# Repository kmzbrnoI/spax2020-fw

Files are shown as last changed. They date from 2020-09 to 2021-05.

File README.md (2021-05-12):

# SPAX 2020

[SPAX](http://fremodcc.sourceforge.net/booster/spaxbooster/index.html)
is a model-railroad DCC signal booster. It is a [well-known hardware
construction from FREMO model railroaders club in
Germany](http://fremodcc.sourceforge.net/booster/spaxbooster/index.html).
This repository contains firmware and PCB design for a new
processor PIC12F629 which is supposed to replace original PIC12F508 SPAX v2
processor **without** changing whole SPAX pcb.

This is a low-cost solution for eliminating old-processor disadvantages.
For future expansion (RailCom etc.) whole new SPAX should be designed.

## Why to change processor?

1. **Weird shortcut detection**
   The old processor measured current as analog signal on digital CPU input.
   This caused bad detection sometimes. The new processor reads analog input
   and uses internal comparator.

2. **Short shortcut-restore time**
   The old processor indicated shortcut when e. g. cars with larger capacitors
   were put on a track. When new processor detects shortcut, it leaves max
   current for a longer time – 20 ms. This is enough time for capacitors to
   charge.

## How to change processor in SPAX

Manufacture `12F629.brd` PCB and replace DIL8 old processor with SMD new
processor on the board.

## Firmware functionality description

Track power supply is restored after 200 ms, 400 ms, 800 ms, 1200 ms, 1200 ms,
...  after overcurrent is detected. This is long-enough time for SPAX cooler to
cool-down stabilizer and H-bridge.

H-bridge ensures that shortcut current will never be more than 3 A.

First 3 tests for overcurrent-restore allow only 5 ms of max current, all next
tests allow max current for 20 ms.

## LEDs

* Red LED = not generating DCC on output
* Green LED = DCC on input

States:

* Green: generating DCC to track
* Red: DCC on input present, but shortcut detected
* Yellow: DCC not on input

## Authors

 * hardware: Jan Horacek
 * firmware: Michal Petrilak, Jan Horacek

## License

The firmware and PCB design is distributed as opensource project under
Apache License v2.0.

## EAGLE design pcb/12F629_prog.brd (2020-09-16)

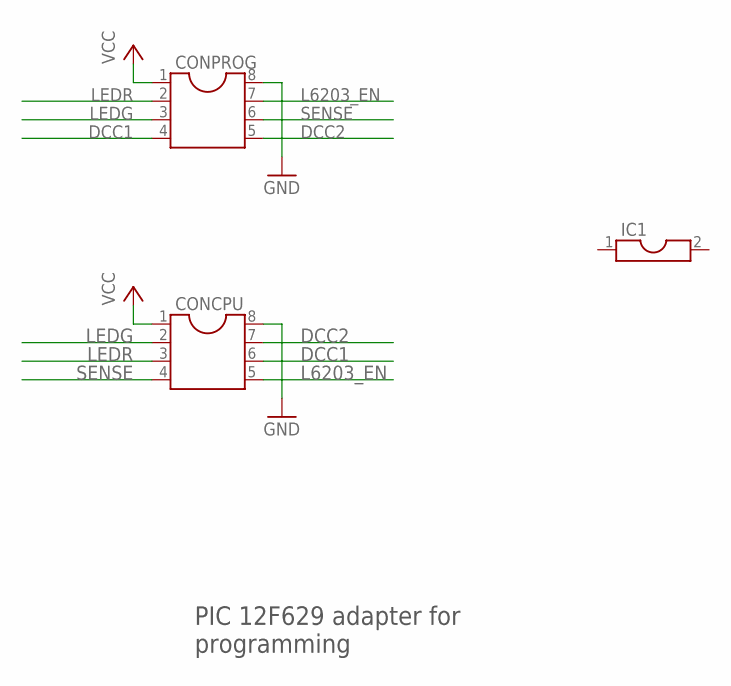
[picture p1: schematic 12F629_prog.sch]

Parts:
CONCPU: DIL8; DIL08
CONPROG: DIL8; DIL08
IC1: DIL2; DIL02

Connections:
DCC1: CONCPU.6, CONPROG.4
DCC2: CONCPU.7, CONPROG.5
GND: CONCPU.8, CONPROG.8
L6203_EN: CONCPU.5, CONPROG.7
LEDG: CONCPU.2, CONPROG.3
LEDR: CONCPU.3, CONPROG.2
SENSE: CONCPU.4, CONPROG.6
VCC: CONCPU.1, CONPROG.1

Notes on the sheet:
PIC 12F629 adapter for programming

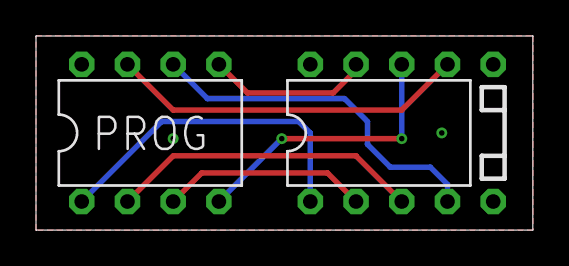
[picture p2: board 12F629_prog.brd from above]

Board: 2 copper layers, 27.6 x 10.8 mm, 3 parts (0 on the bottom side), 8 nets.

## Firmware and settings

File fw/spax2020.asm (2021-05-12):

;      SPAX2020
; ---------------------
; Spax s lépe řešenou detekcí zkratu
;
; author: Michal Petrilak, Jan Horacek
; assembler: gpasm
;
; For simulation, marked lines in ‹init› must be commented out
;
; Toff = 30 ms, 2.5 W on stabilizer when short-circuit
        list p=12f629
        #include <p12f629.inc>
        errorlevel -305,-302
        __CONFIG  _BODEN_ON & _CP_OFF & _WDT_OFF & _MCLRE_OFF & _PWRTE_OFF & _INTRC_OSC_NOCLKOUT & 31FF

;GP0    enable booster
;GP1    sense (CIN-)
;GP2    DCC_in2
;GP3    DCC_in1
;GP4    led green
;GP5    led red

; BITY/PINY
#define     DCC_in1     GPIO,3
#define     DCC_in2     GPIO,2
#define     overC       CMCON,COUT

#define     led_green   GP_ram,4
#define     led_red     GP_ram,5
#define     drv_en      GP_ram,0

; Main timer 1
CTIMET1     equ     0x100 - d'20'       ; master timer T = 5.12 ms (4 MHz / 4 / 1 / 256 / 20)
CTIMET1L    equ     0x100 - d'100'      ; |
DCC_CHCK    equ     d'10'
DCC_post    equ     d'3'                ; timer postscaler

; Timer 0 for reading short-circuit detection
CTIMET0     equ     0x100 - d'125'      ; timer T = 500 us

short_t1    equ     d'04'               ; short-circuit react time (first & permanent) 04 = 20 ms
short_t2    equ     d'01'               ; short-circuit react time (repeated) 01 =  5 ms
set_res_t0  equ     d'020'              ;   (100 ms) delays between restore attempts
set_res_t1  equ     d'040'              ; | (200 ms)
set_res_t2  equ     d'080'              ; | (400 ms)
set_res_t3  equ     d'120'              ; | (600 ms))

GP_TRIS     equ     b'00001110'         ; only analog inputs: GP0, GP1
GP_INI      equ     b'00000000'         ; all zero
OPTION_INI  equ     b'10000001'         ; Option reg: no pull-up, falling GP2, TMR0 prescaler 4
CMCON_INI   equ     b'00000100'         ; comparator GP1 input,use Vref, no output
INTCON_INI  equ     b'10001000'         ; interrupt enable from GPchange, global enable
VRCON_INI   equ     b'10001000'         ; Vref enabled, V=2.5V @ Vcc=5V
IOC_INI     equ     b'00001100'         ; interrupt on change GPIO 2,3
T1CON_INI   equ     b'00000001'         ; T1 internal clock, prescaler 1, LP off, gate allways on, running

#define     BANK0       bcf STATUS,RP0
#define     BANK1       bsf STATUS,RP0

#define     IRQ_IOC_ENA bsf INTCON, GPIE
#define     IRQ_IOC_DIS bcf INTCON, GPIE
#define     IRQ_IOC_CLR bcf INTCON, GPIF

cblock 0x20
            ; reserver for DCC cedocer
endc

cblock 0x30
            tmpw
            tmps
            GP_ram
            flags
            flags_DCC
            state
            DCC_cnt
            LED_cnt
            short_cnt
            DCCtmr_post
            restore_state     ; output restoring state (how long to wait)
            restore_cnt       ; output restoring counter (4xT1)
            overload_debouncer
            over_cnt
endc

#define     fDCC1_hi    flags_DCC,0 ; DCC test internal flags
#define     fDCC1_lo    flags_DCC,1
#define     fDCC2_hi    flags_DCC,2
#define     fDCC2_lo    flags_DCC,3
#define     fTimer      flags,0
#define     fblik       flags,1
#define     fblikmask   b'00000010'
#define     fDCCok      flags,2     ; delayed flag DCC
#define     fDCCtstok   flags,3     ; fast test DCC
#define     foverR      flags,4     ; return value of overload
#define     fover       flags,5     ; long-time state of overload (poll this value to ask)

#define     s_drv_en     state,0; output state
#define     s_overcur    state,1; overcurrent detected


; ****************************
; **         START          **
; ****************************

            org 0                   ; entry point
            movlw   GP_INI          ; reset GPIO
            movwf   GPIO
            movwf   GP_ram
            goto    init            ; goto init

            org 4
irq:        movwf   tmpw            ; irq
            swapf   STATUS, w       ; save state
            movwf   tmps

            btfsc   INTCON,GPIF
            goto    irq_dcc
            nop                     ; unknown interrupt
            goto    irq_end

irq_dcc:    IRQ_IOC_CLR             ; test DCC pins and set flags
            btfsc   DCC_in1
            bsf     fDCC1_hi
            btfss   DCC_in1
            bsf     fDCC1_lo
            btfsc   DCC_in2
            bsf     fDCC2_hi
            btfss   DCC_in2
            bsf     fDCC2_lo

irq_end:    swapf   tmps,W          ; restore state
            movwf   STATUS
            swapf   tmpw,f
            swapf   tmpw,w
            retfie                  ; irq end

irq_notused:
            goto    irq_end

; ****************************
; **       Tabulky          **
; ****************************

ref_tab:    ANDLW   0x03
            ADDWF   PCL, F
            RETLW   set_res_t0
            RETLW   set_res_t1
            RETLW   set_res_t2
            RETLW   set_res_t3

jump_state: MOVF    state,w
            ANDLW   0x03
            ADDWF   PCL, F
            GOTO    state_0          ; invalid
            GOTO    state_1          ; run
            GOTO    state_2          ; poweroff
            GOTO    state_3          ; recovery

;state diagram:
;    power on = state 0 -> state 1
;    short    = state 1 -> state 2
;               state 3 -> state 2
;    wait     = state 2 -> state 3
;    no short = state 3 -> state 1


; ****************************
; **         INIT           **
; ****************************

init:                               ; init
            BANK1
            movlw   GP_TRIS
            movwf   TRISIO
            call    0x3FF          ; get OSCCAL value; comment out this for simulation
            movwf   OSCCAL         ; comment out this for simulation
;            nop
;            nop
            movlw   IOC_INI
            movwf   IOC
            movlw   VRCON_INI
            movwf   VRCON
            movlw   OPTION_INI
            movwf   OPTION_REG
            BANK0
            movlw   CMCON_INI
            movwf   CMCON
            movlw   0x5f            ; clear RAM (0x20 - 0x5f)
            movwf   FSR
clrRAM:     decf    FSR,w
            movwf   FSR
            clrf    INDF

            sublw   0x20
            btfss   STATUS, C
            goto    clrRAM

            movlw   T1CON_INI       ; enable timer 1
            movwf   T1CON           ; |
            movlw   0xff            ; |
            movwf   TMR1H           ; |
            movlw   DCC_post        ; |
            movwf   DCCtmr_post     ; |
            IRQ_IOC_ENA

            movlw   0xff            ; enable timer 0
            movwf   TMR0            ; |

            movlw   INTCON_INI      ; enable interrupts
            movwf   INTCON
init_end:

; ****************************
; **       Main Loop        **
; ****************************

main:
            movfw   GP_ram          ; copy GP_ram to outputs
            movwf   GPIO            ; |
            movfw   GPIO            ; read GPIO (for IOC work)

            call    DCCtstfast
            call    handleLed
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

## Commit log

2020-09-16 Add PCB.
    [12F629.brd, 12F629.sch, 12F629_prog.brd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]
2021-05-11 Add proper deboucing for overload detection pin.
    Read pin 8 times (each 2 us), consider short-circuit when >2 reads
    indicate short-circuit.
    [spax2020.asm]
2021-05-12 Remove unused interrupt.
2021-05-12 Remove ununsed LED blinking.
2021-05-12 Add fuses config file.
2021-05-12 Enable timer 0 @ 500 us.
2021-05-12 Calculate overload in timer.
2024-08-02 fuses.conf for new minipro v0.7.
